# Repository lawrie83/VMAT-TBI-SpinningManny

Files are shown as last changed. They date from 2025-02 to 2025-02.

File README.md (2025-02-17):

This is an indexed overlay board to allow indexed 180 deg roations of patients during radiotherapy. aka "Spinning Manny"

----parts list----

---Custom carbon fiber parts---

1 Custom design carbon fiber board with wall thickness 1.5mm and foam core. e.g. made by Hillsdale composites.

2 custom drilled and cut 1/8" thick Carbon fiber plate (Raw material McMaster-carr part 9266K14)

---3D Printable Plastic parts---

3 indexing pin (need 4x)

4 Plastic_disc (need 1x)

5 locker-v2  (need 2)

6 Feet parts (need 12-16x)

11 Optional vacbag indexer (hollow 3D printed bar similar to Bionix bar)

---Other McMaster-Carr parts---

7 - 90611A121 - Screw-Mount Nut 
          - https://www.mcmaster.com/90611A121/
          - need 1x
          
8 - 91970A753 - Bolt for above 
          - https://www.mcmaster.com/91970A753/
          - need 1x
          
9 - 93143A537 - Aluminum Decorative Round Head Slotted Screw (need 6 screws, comes in box of 25)
          - https://www.mcmaster.com/93143A537/
          - Al screws are preffered over Nylon due to higher shear strength, and over over metals due to lower density 2.7 vs 8 g/cc)
          - need 6x

10 - 9266K81   - 6" x 6" x 1/32" PTFE (Teflon) sheet 
          - https://www.mcmaster.com/9266K81/
          - to be glued between rotating surfaces to reduce friction
          - need 1x

---extra---

Silicone Adhesive e.g. https://www.amazon.com/Permatex-80050-Silicone-Adhesive-Sealant/dp/B0002UEPVI

Spare Varian compatible Aluminum indexing bar to attach part 5 to lock the couch overlay.

System has been tested with up to 350lbs of weight. Recommend three RTT's to hold, two at head end on at foot end.

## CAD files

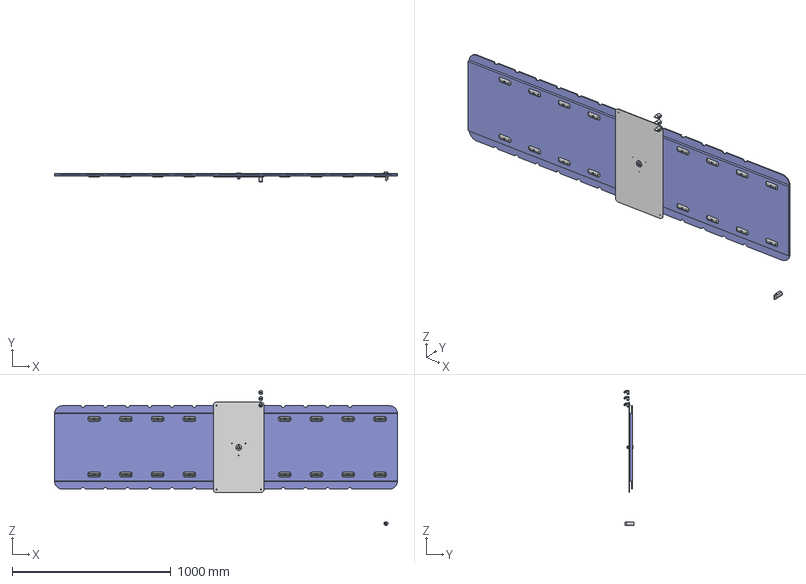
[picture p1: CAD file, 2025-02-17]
Spinning_Manny_2025 v3.step
2160.0 x 65.5 x 850.6 mm
Overlay Board
Index Plate
McMaster-Car Parts
Feet

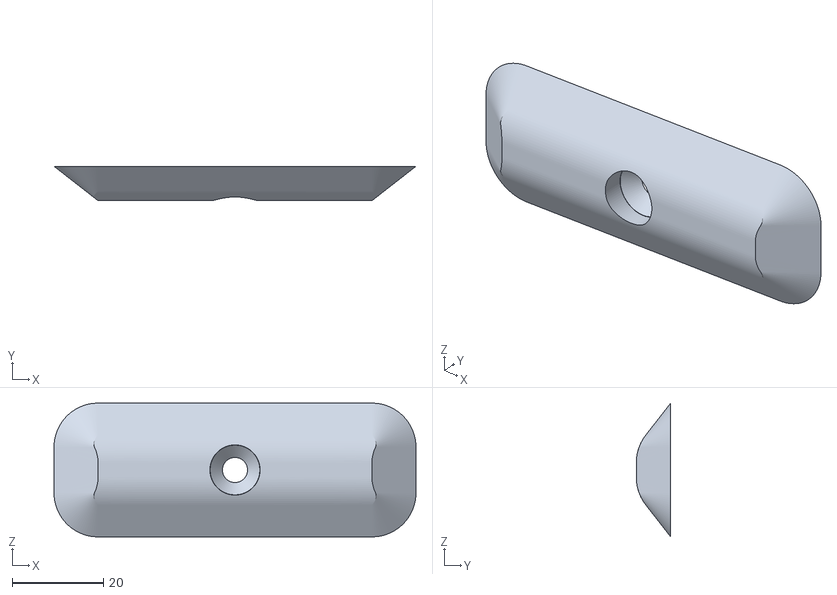
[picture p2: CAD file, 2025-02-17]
6 foot.stl
79.3 x 7.53 x 29.3

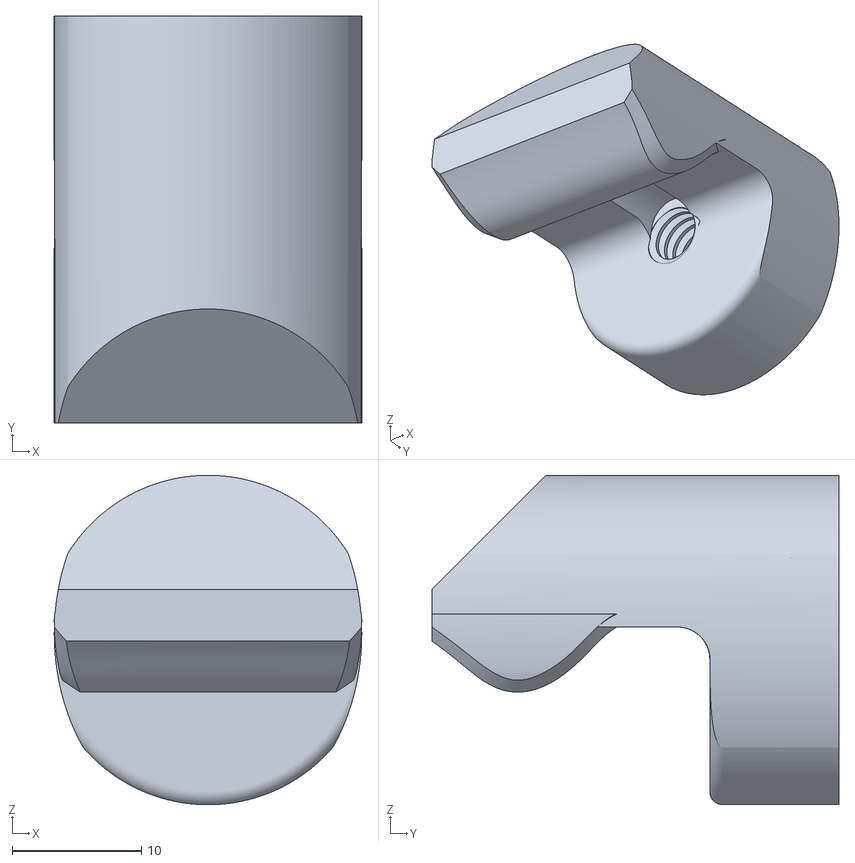
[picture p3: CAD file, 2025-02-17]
3 indexing pin -Standard.stl
23.8 x 31.5 x 25.5

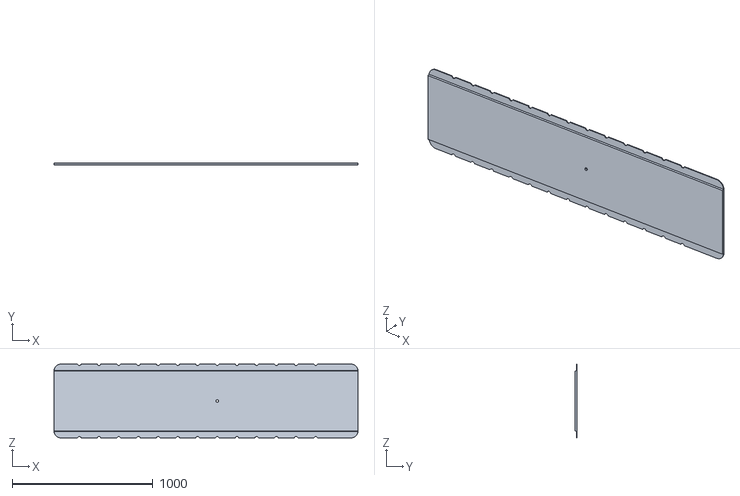
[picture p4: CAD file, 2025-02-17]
1 overlay board.stl
2160.0 x 15.0 x 525.0

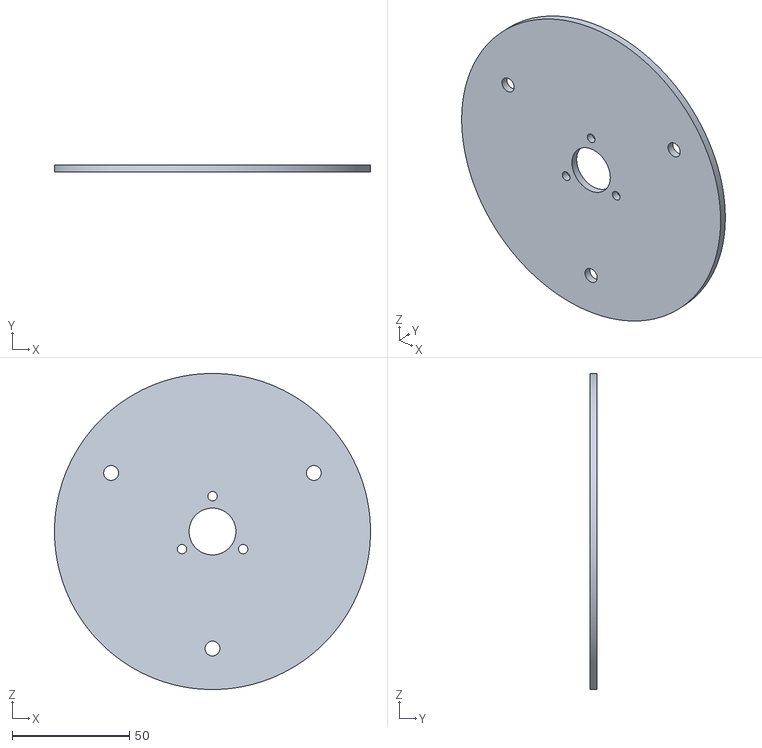
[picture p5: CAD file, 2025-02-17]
4 PLA_disc.stl
135.0 x 3.18 x 135.0

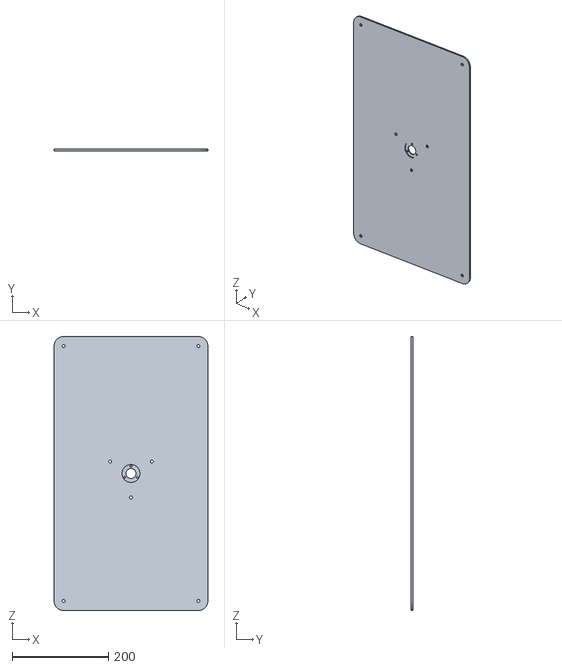
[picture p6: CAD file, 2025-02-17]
2 CFRP_index_plate_2023 (MCMaster 9266K14).stl
320.0 x 3.17 x 570.0

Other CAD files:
3a indexing pin - Tighter.stl
3b indexing pin - looser.stl

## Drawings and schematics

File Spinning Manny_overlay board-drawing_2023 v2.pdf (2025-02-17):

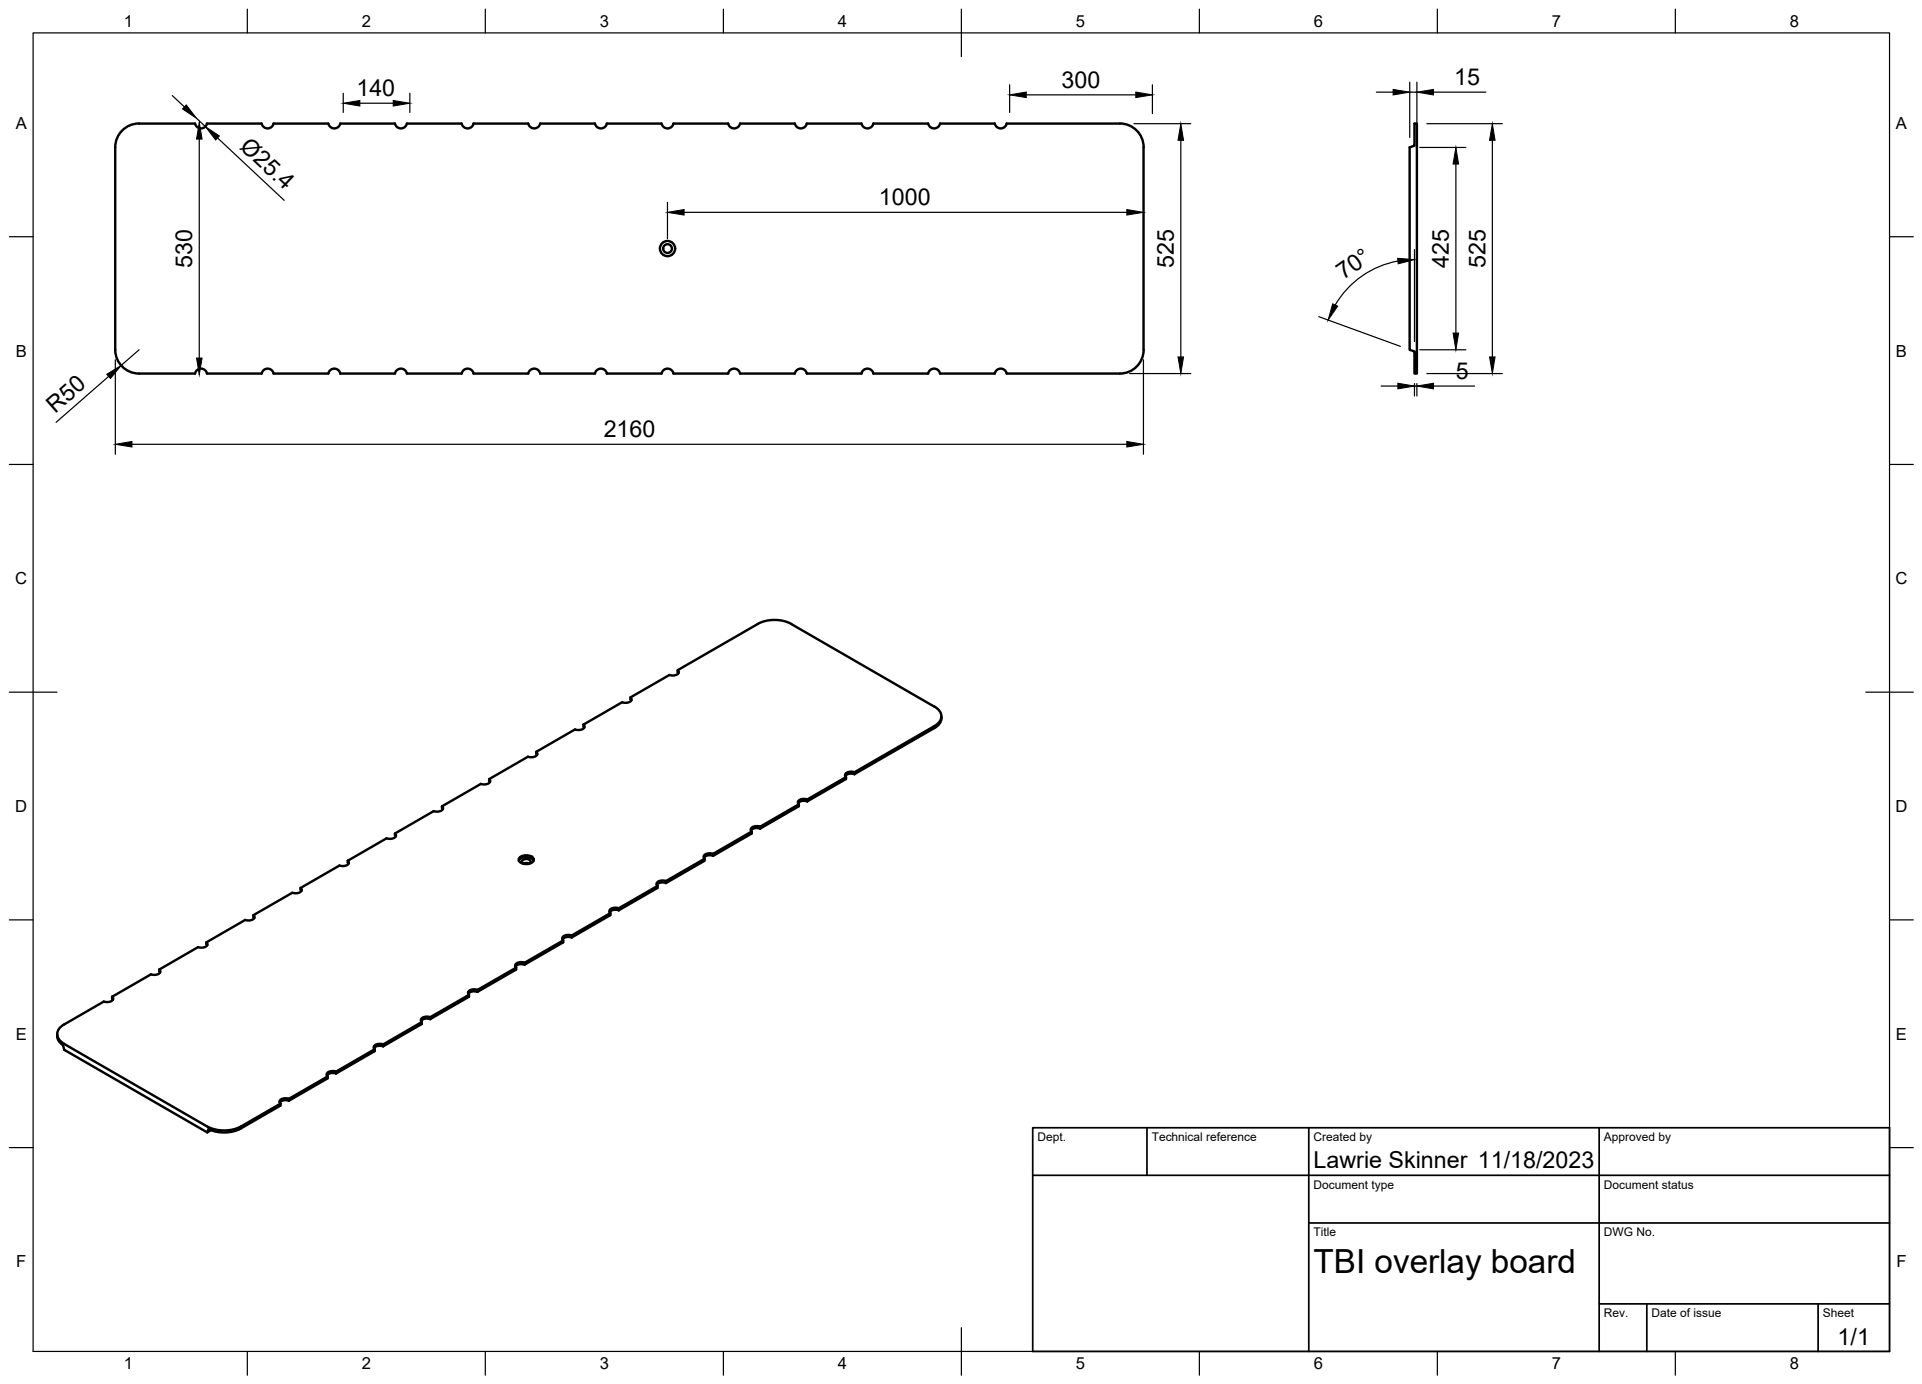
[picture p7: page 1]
Title; DWG No.; Rev.; Date of issue; Sheet; Lawrie Skinner 530 R50 525

Dept. | Technical reference | Created by 11/18/2023 | Approved by

Document type | Document status

TBI overlay board
